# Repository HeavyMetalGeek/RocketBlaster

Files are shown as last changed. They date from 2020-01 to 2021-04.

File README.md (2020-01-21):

# RocketBlaster - Air Powered Rocket Launcher

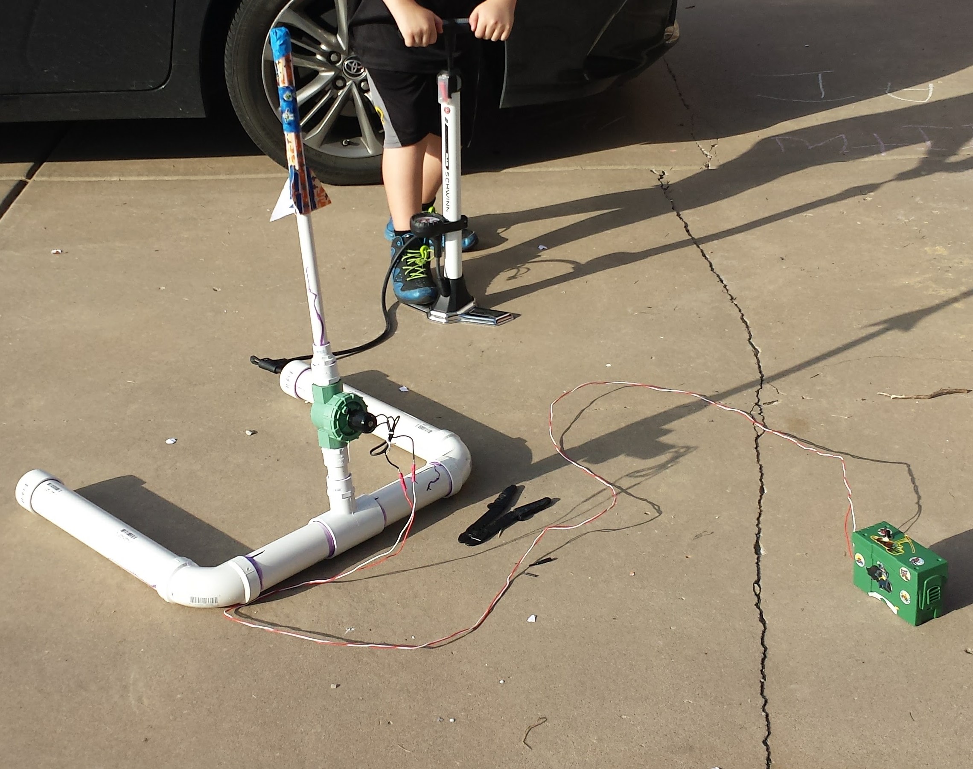
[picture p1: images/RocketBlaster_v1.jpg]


### Current Requirements:

- Supplied with 18V-24V, likely with two 9V batteries
- Main toggle switch for controlling power to the system (lights red LED when closed)
- Secondary toggle switch will act as a safety switch (lights yellow LED when closed)
- A momentary switch will be used for triggering the launch (lights green LED during launch sequence)
- When the launch sequence is triggered, the microcontroller triggers playback of an audio file from the DFPlayer Mini (DFR0299) module
- After a time that correlates to the end of the audio playback, triggers a MOSFET to switch the 18V-24V source for the solenoid valve

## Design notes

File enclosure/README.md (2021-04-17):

# RocketBlaster - Enclosure Design

### Design Parameters:
* Design based on PCB design
* Design for home FDM printing
* Utilize heat-set threaded inserts for threaded joints
    - Design for use of [these inserts](https://www.mcmaster.com/heat-set-inserts/thread-insert-style~standard/), using 0.5mm undersize from OD
* Design for use of metric socket head screws, M3 or larger where possible
* Mount PCB, switches, and buttons
    - Power switch
    - Safety switch
    - Launch momenary switch/button
* Expose LEDs
* Potentially expose SD card and ISP header

### Current State:
* No steps taken

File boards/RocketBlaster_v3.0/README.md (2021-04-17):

# RocketBlaster - PCB Design

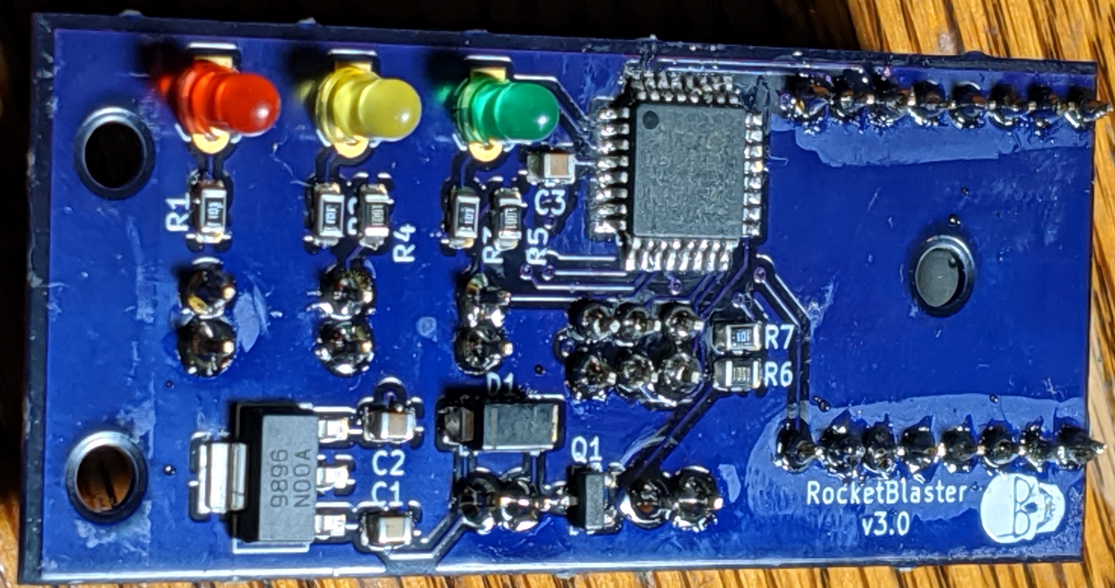
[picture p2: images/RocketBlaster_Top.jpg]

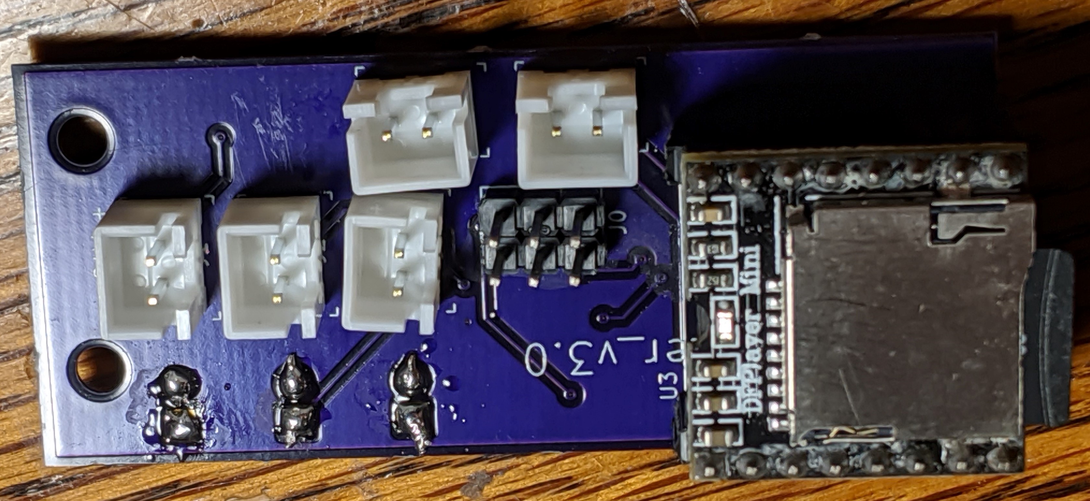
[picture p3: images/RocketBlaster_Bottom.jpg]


### Design Parameters:
* Small form factor to reduce cost
* MCU programmed via ISP header
* Use JST connectors to connect to switches on enclosure
* Intended to mount to enclosure top, so that LEDs pertrude
* DFPlayer plugs into headers on bottom of PCB
* SD card in DFPlayer stores audio files

### Current State:
* PCB designed in KiCAD
* Prototype boards fabricated
* Components sourced and acquired
* 1 prototype assembled and ready for firmware testing

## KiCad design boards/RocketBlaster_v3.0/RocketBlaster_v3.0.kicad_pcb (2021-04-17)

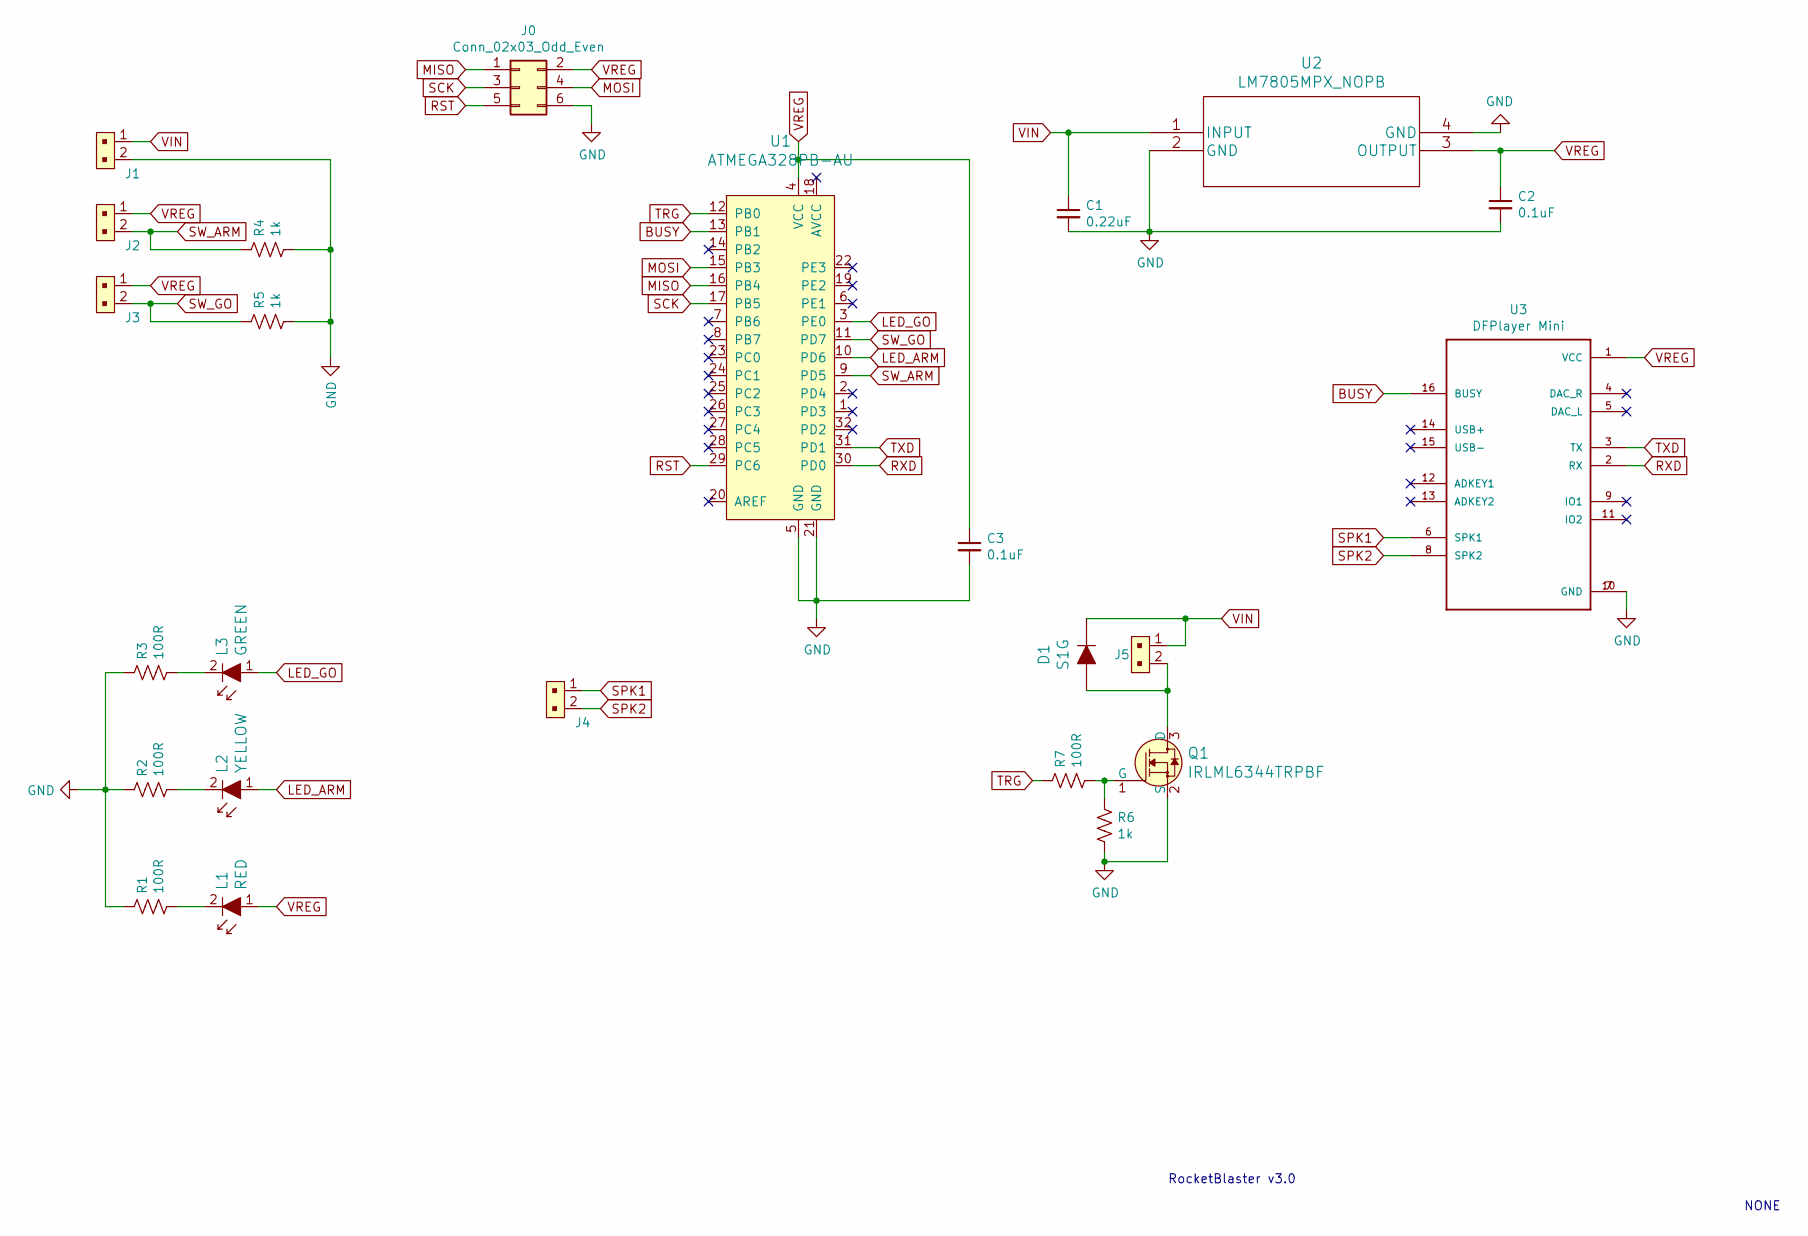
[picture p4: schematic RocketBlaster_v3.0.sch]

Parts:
C1: 0.22uF; C_0805_2012Metric
C2, C3: 0.1uF; C_0805_2012Metric
D1: S1G; DO-214AC; MPN S1G; Digi-Key_PN S1GFSCT-ND
J0: Conn_02x03_Odd_Even; PinHeader_2x03_P2.54mm_Vertical
J1, J2, J3, J4, J5: B2B-XH-A_LF__SN_; PinHeader_1x2_P2.5mm_Drill1.1mm; MPN B2B-XH-A(LF)(SN); Digi-Key_PN 455-2247-ND
L1: RED; LED_3mm_Radial; MPN 151033RS03000; Digi-Key_PN 732-5013-ND
L2: YELLOW; LED_3mm_Radial; MPN 151033RS03000; Digi-Key_PN 732-5013-ND
L3: GREEN; LED_3mm_Radial; MPN 151033RS03000; Digi-Key_PN 732-5013-ND
Q1: IRLML6344TRPBF; SOT-23-3; MPN IRLML6344TRPBF; Digi-Key_PN IRLML6344TRPBFCT-ND
R1, R2, R3, R7: 100R; R_0805_2012Metric
R4, R5, R6: 1k; R_0805_2012Metric
U1: ATMEGA328PB-AU; TQFP-32_7x7mm; MPN ATMEGA328PB-AU; Digi-Key_PN ATMEGA328PB-AU-ND
U2: LM7805MPX_NOPB; LM7805MPX&slash_NOPB
U3: DFPlayer Mini; MODULE_DFR0299

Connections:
BUSY: U1.13 (PB1), U3.16 (BUSY)
GND: C1.2, C2.2, C3.2, J0.6, J1.2, Q1.2 (S), R1.1, R2.1, R3.1, R4.2, R5.2, R6.2, U1.5 (GND), U1.21 (GND), U2.2 (GND), U2.4 (GND), U3.7 (GND), U3.10 (GND)
LED_ARM: L2.1, U1.10 (PD6)
LED_GO: L3.1, U1.3 (PE0)
MISO: J0.1, U1.16 (PB4)
MOSI: J0.4, U1.15 (PB3)
unnamed: D1.A, J5.2, Q1.3 (D)
unnamed: L1.2, R1.2
unnamed: L2.2, R2.2
unnamed: L3.2, R3.2
unnamed: Q1.1 (G), R6.1, R7.2
RST: J0.5, U1.29 (PC6)
RXD: U1.30 (PD0), U3.2 (RX)
SCK: J0.3, U1.17 (PB5)
SPK1: J4.1, U3.6 (SPK1)
SPK2: J4.2, U3.8 (SPK2)
SW_ARM: J2.2, R4.1, U1.9 (PD5)
SW_GO: J3.2, R5.1, U1.11 (PD7)
TRG: R7.1, U1.12 (PB0)
TXD: U1.31 (PD1), U3.3 (TX)
VIN: C1.1, D1.K, J1.1, J5.1, U2.1 (INPUT)
VREG: C2.1, C3.1, J0.2, J2.1, J3.1, L1.1, U1.4 (VCC), U2.3 (OUTPUT), U3.1 (VCC)

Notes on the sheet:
NONE
RocketBlaster v3.0

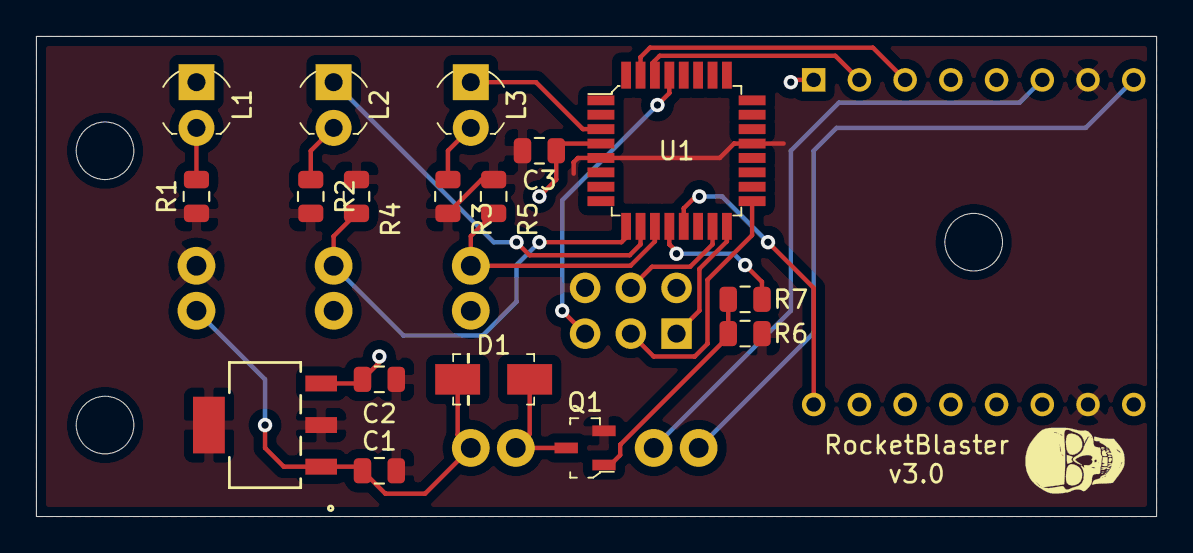
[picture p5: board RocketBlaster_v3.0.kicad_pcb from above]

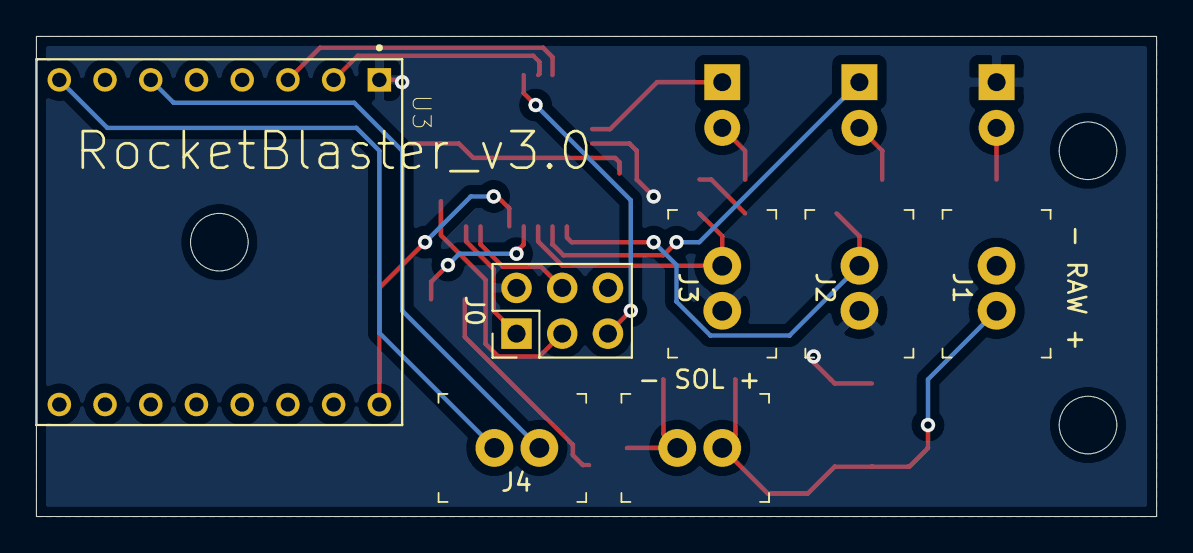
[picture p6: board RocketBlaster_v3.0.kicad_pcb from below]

Board: 2 copper layers, 62.2 x 26.7 mm, 24 parts (7 on the bottom side), 22 nets.

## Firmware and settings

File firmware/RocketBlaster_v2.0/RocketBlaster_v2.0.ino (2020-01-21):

#include "SoftwareSerial.h"
#include "DFPlayer.h"
#define Start_Byte     0x7E
#define Version_Byte   0xFF
#define Command_Length 0x06
#define End_Byte       0xEF
#define Acknowledge    0x00

const byte rxPin = 11;
const byte txPin = 10;
const byte relayPin = 8;
const byte switchPin = 9;
const byte safetyPin = 7;
const byte ledPin = 13;
DFPlayer player(11, 10);
 
void setup () 
{
  pinMode(rxPin, INPUT);
  pinMode(txPin, OUTPUT);
  pinMode(relayPin, OUTPUT);
  pinMode(switchPin, INPUT);
  pinMode(safetyPin, INPUT);
  Serial.begin(9600);
  
  digitalWrite(relayPin, HIGH);

  // Send request for initialization parameters
  player.initialize();
  
  // Set sound to 30 of 48
  player.volumeSet(0x1E);
  
  Serial.println("Setup complete");
  
  // LED indicator for "ready" status
  indicate_ready();
}
 
void loop () 
{
  bool safety = false;
  bool launch = false;

  if(digitalRead(switchPin) == HIGH && digitalRead(safetyPin) == HIGH)
  {
    if(player.serial.available()>=10)
    {
      Serial.println("Launch sequence start");
      launch_sequence();
    }
    else
    {
      Serial.println("Busy, try again later...");
      // LED indicator for "busy" status
      indicate_busy();
    }
  }
}

void launch_sequence()
{
  digitalWrite(ledPin, HIGH);
  
  // Play track 2
  player.track(0, 2);
  delay(11000);
  
  // Pause track
  Serial.println("Pausing");
  player.pause();
  
  // Relay activate (launch)
  Serial.println("Launching");
  digitalWrite(relayPin, LOW);
  delay(300);
  
  // Relay deactivate
  digitalWrite(relayPin, HIGH);
  
  // Continue track
  player.play();
  delay(2600);
  
  // Stop play
  Serial.println("Stopping");
  player.stop();
  
  digitalWrite(ledPin, LOW);
}

void indicate_ready()
{
  for(byte i=0; i<5; i++)
    {
      digitalWrite(ledPin, HIGH);
      delay(250);
      digitalWrite(ledPin, LOW);
      delay(250);
    }
}

void indicate_busy()
{
  for(byte i=0; i<3; i++)
    {
      digitalWrite(ledPin, HIGH);
      delay(500);
      digitalWrite(ledPin, LOW);
      delay(500);
    }
}

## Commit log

2020-01-21 Added image for current state of the schematic
    [RocketBlaster_v3.0.sch]
2020-01-21 Added firmware and updated readme
    [RocketBlaster_v3.0.kicad_pcb, RocketBlaster_v3.0.sch]
2020-01-23 Corrections to schematic and PCB parameters for OSH Park
    [RocketBlaster_v3.0.kicad_pcb, RocketBlaster_v3.0.sch]
2021-04-17 Update KiCAD files, add enclosure folder, and add README info
    [RocketBlaster_v3.0.kicad_pcb, RocketBlaster_v3.0.sch]

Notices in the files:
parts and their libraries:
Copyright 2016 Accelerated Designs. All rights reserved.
